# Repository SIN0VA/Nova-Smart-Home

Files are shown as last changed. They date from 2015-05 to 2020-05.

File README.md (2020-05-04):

# Nova Smart Home
## Introduction 
This is a Home Automation project that I did for my final year, it uses a Raspberry Pi that acts as a central board for controling a bunch of Arduino UNO  cards (RF Nodes). For this project I made 4 types of these RF nodes.  

  1. [RF Switches](Arduino Sketches and Schematics/Arduino RF Controlled Lightswitch/) (to switch any electrical appliance, it's implemented here for lights only).  
  2. PIR Nodes (A bunch of Arduino's coupled with PIR detectors for autolights).  
  3. A Sensor Node (An Arduino with special [Sensor Shield](https://github.com/SIN0VA/Nova-Smart-Home/tree/master/Arduino%20Sketches%20and%20Schematics/Arduino%20Sensor%20Node) : to collect readings on temperature, humidty and somke detection ).  
  4. An HVAC Controller (An Arduino with a special [HVAC Shield](Arduino Sketches and Schematics/Arduino Sensor Node/) to   control a "Conventional HVAC System"). I haven't tested this one, so you should tread carefully.  
<p align="center">
 
</p>  

The communication between the Raspberry Pi and the other nodes is achieved using the NRF24L01 RF module, each type of the RF nodes has its own Shield, except the light switch which is a RF light switch (Arduino compatible) based on an Atmega328p MCU and a relay.  

## Software Stack 
### Arduino Sketches
Each RF node has its owns sketch, the two types of nodes that send data to the Raspberry Pi are the PIR Node and the Sensor Node, the other two (the HVAC controller and the RF light switch) will only recieve commands from the Raspberry Pi.  

1. [RF Switch Sketch](Arduino Sketches and Schematics/Arduino RF Controlled Lightswitch/RF LightSwitch/RF LightSwitch.ino).  
2. [PIR Node Sketch](Arduino Sketches and Schematics/Arduino RF Motion Detection/Motion Detection/Motion Detection.ino).  
3. HVAC Controller Sketch (haven't made this one).  
4. [Sensor Node Sketch](Arduino Sketches and Schematics/Arduino Sensor Node/SensorNode/SensorNode.ino).  

If you can't make the Shields, just follow the schematics of every Shield and use wires (but you have to make the RF Switch to control lights).
### Raspberry Pi  
<p align="center">
  
</p>

Just to introduce the workings of this project a little bit, there are two programs ; a Node.JS app  which is an Express Web Server so people can turn off/on lights and things like that, If you're familiar with NodeJS Express check the two main files of the server the [ExpressJS Routes](HomeControlServer/routes/index.js) file and the [ExpressJS App ](HomeControlServer/app.js) file. For security reasons, this server uses SSL encryption and asks for a password and a username everytime someone tries to access this server.
The second app is a [Control Daemon](ControlDaemon/NovaHomeDaemon.cpp) coded with C++, this one controls and handles the requests from NodeJS Web Server (IPC via ZMQ sockets) and other RF nodes (via NRF24L01), it also performs the Home Automation side of things.
  
### Control Daemon Configuration  
The Nova Control Daemon is small process that controls the different RF nodes using the RF interface (NRF24L01), it waits for requests from the web server (when a user turn on/off/auto the lights from the browser). This is the heart of this system, it's the decision making engine of this Smart Home, I should note that temprature control uses a simple non-tested algorithme so this area might need some improvements. The autolights (based on motiond detection) and manual light control (using web server) work flawlessly. But this app needs a configuration, for now to configure the control daemon you have to check its [configuration file](/ControlDaemon/NovaHomeDaemon.cfg), I commented on every lines so it's pretty straightforward, later I will add the ability to configure the Dameon from a browser.

### Web Server How-To Install  
Just install NodeJS and copy the HomeControlServer. (The complete guide is coming...)

### Nova Home Daemon How-To Install  
Install the dependencies and compile NovaHomeDaemon. (Wait for the complete tutorial, it's gonna be easy)

### HomeRF Protocol 
I made this protocol to secure and manage the exchange of data and commands between the Raspberry Pi and the RF Nodes, this protocol sits on top of the RF24Network Library. It uses AES-128 for encryption and HMAC-SHA1 for authentication.
Here is a diagram for the HomeRF paquet and the structure of data encrypted inside of it :  
<p align="center">
  
</p>  

### Hardware Stack  
(Schematics explanations and design choices,...)

### What's working :  
These functions are tested and working properly :  
1. Autolights (motion detection, disabled/enabled at night/day).
2. Geolocation (sets the time to enable/disable the autolights function).  
3. Manual lights control from any web browser computers, tablets or smarthphones (thanks to responsive design).  
4. Secure Encryprion of RF data using the AES-128 Standard.  
5. SMS Alert in case of fire or smoke detection.  

### What's not Working :  
1. HMAC-SHA1 Authentication (gotta fix it).  
2. I haven't tested temprature and humidity control (the algorithme needs some improvment maybe a PID code).  
3. Call2Report (call the Smart Home and then it will report back with an SMS), this one is not tested.  

### IMPORTANT NOTE !
You can't sell, publish any of the code in here, it's free software under the GPLv3 licence.
Read the licence for more information.
When you use this project or any code of it especially in an academic paper, you have to link to this website.

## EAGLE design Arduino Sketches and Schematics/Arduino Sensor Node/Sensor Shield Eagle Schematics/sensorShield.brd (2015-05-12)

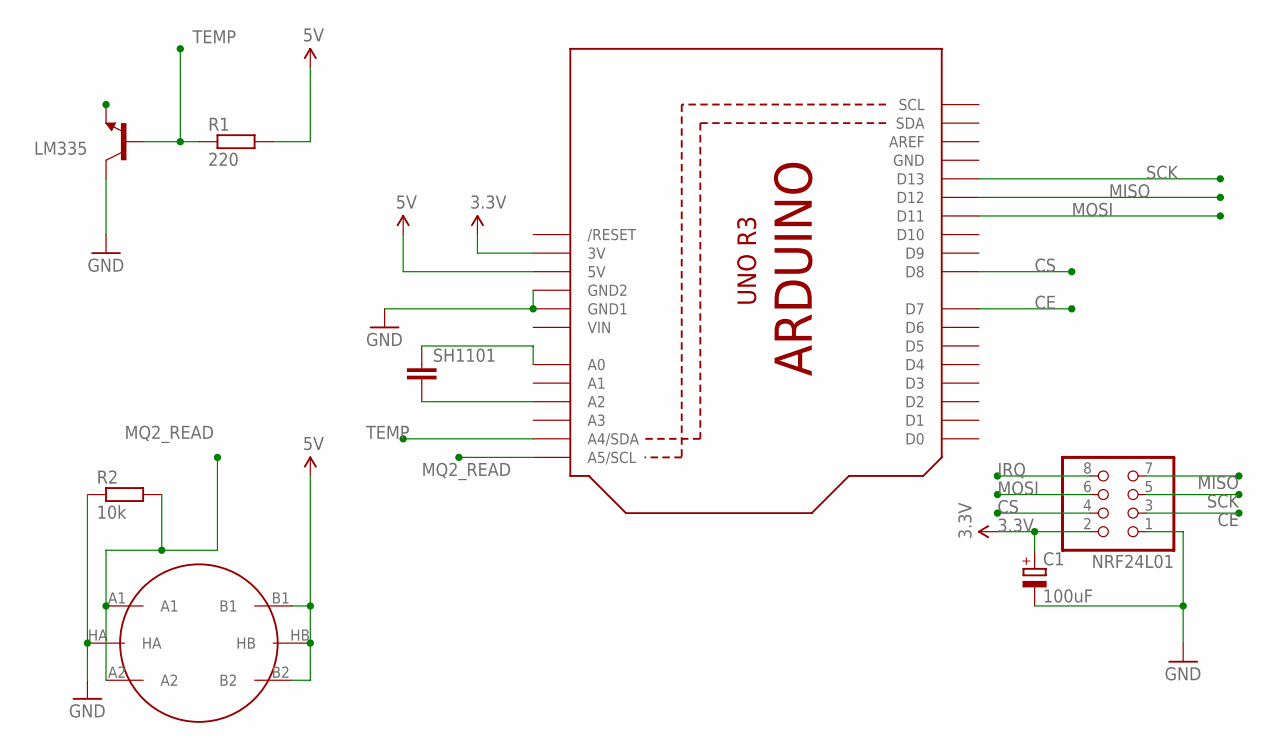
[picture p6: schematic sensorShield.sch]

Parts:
C1: 100uF; E5-6
LM335: TRANSISTOR_NPNTO-92-AMMO; TO-92-AMMO
NRF24L01: PINHD-2X4; 2X04
Q1: ARDUINOR3-NOIOREF-NOTEXT; ARDUINOR3-NOTEXT-NOIOREF
R1: 220; 0204/7
R2: 10k; 0204/7
SH1101: C-EU050-024X044; C050-024X044
U$1: METHANE_SENSOR; MQ-3

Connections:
3.3V: C1.+, NRF24L01.2, Q1.3V
5V: Q1.5V, R1.2, U$1.B1, U$1.B2, U$1.HB
CE: NRF24L01.3, Q1.D7
CS: NRF24L01.4, Q1.D8
GND: C1.-, LM335.3 (C), NRF24L01.1, Q1.GND, Q1.GND1, Q1.GND2, R2.1, U$1.HA
IRQ: NRF24L01.8
MISO: NRF24L01.7, Q1.D12
MOSI: NRF24L01.6, Q1.D11
MQ2_READ: Q1.A5 (A5/SCL), R2.2, U$1.A1, U$1.A2
unnamed: Q1.A2, SH1101.2
unnamed: Q1.A0, SH1101.1
SCK: NRF24L01.5, Q1.D13
TEMP: LM335.2 (B), Q1.A4 (A4/SDA), R1.1
VIN: Q1.VIN

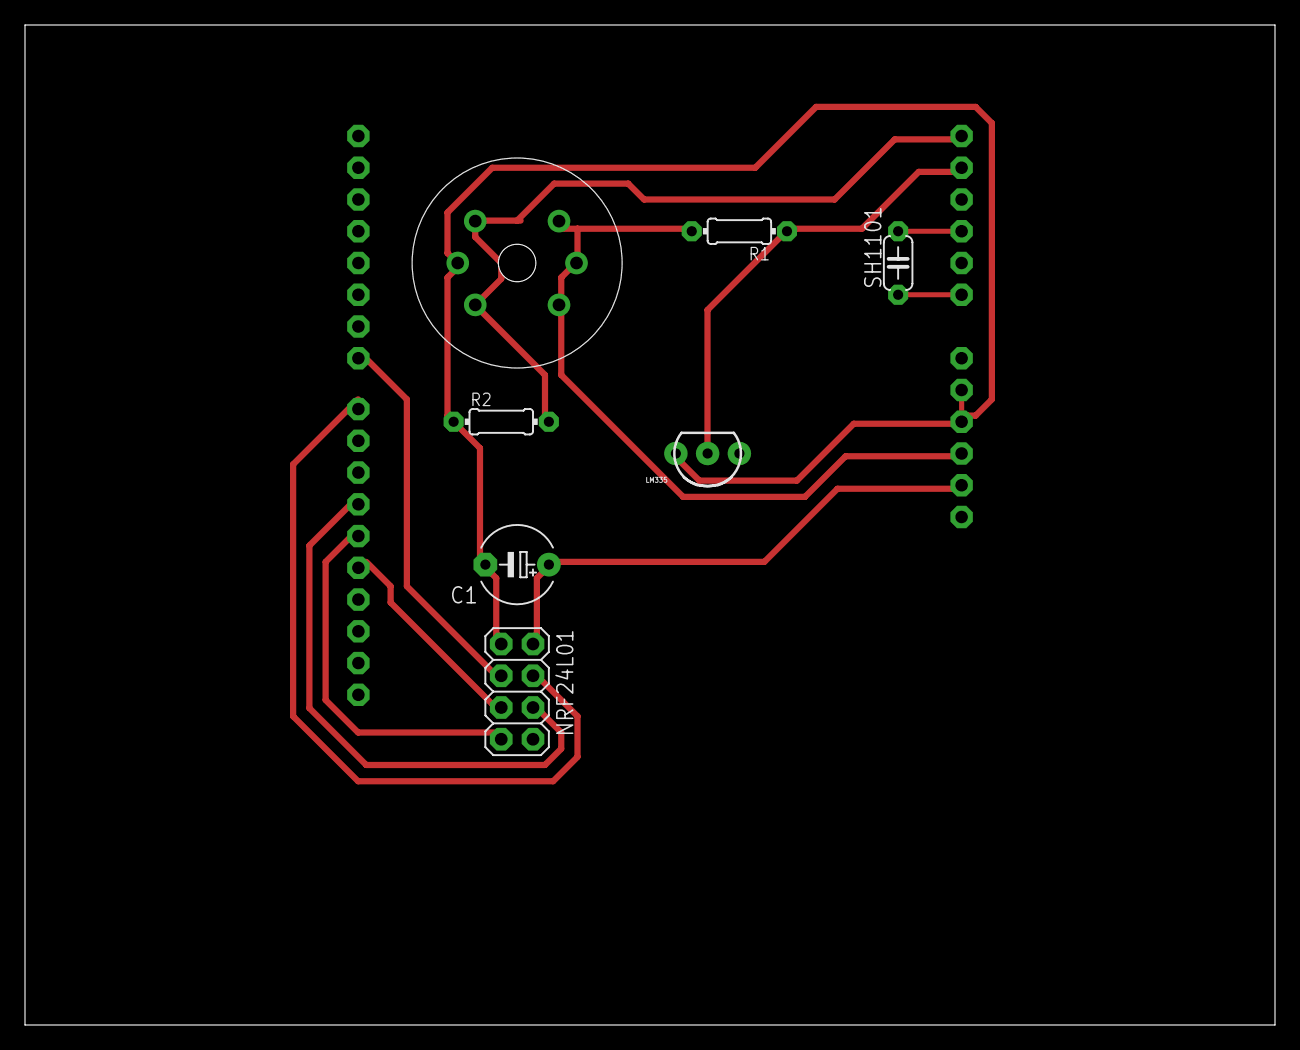
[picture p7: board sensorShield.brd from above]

Board: 2 copper layers, 100.0 x 80.0 mm, 8 parts (0 on the bottom side), 12 nets.

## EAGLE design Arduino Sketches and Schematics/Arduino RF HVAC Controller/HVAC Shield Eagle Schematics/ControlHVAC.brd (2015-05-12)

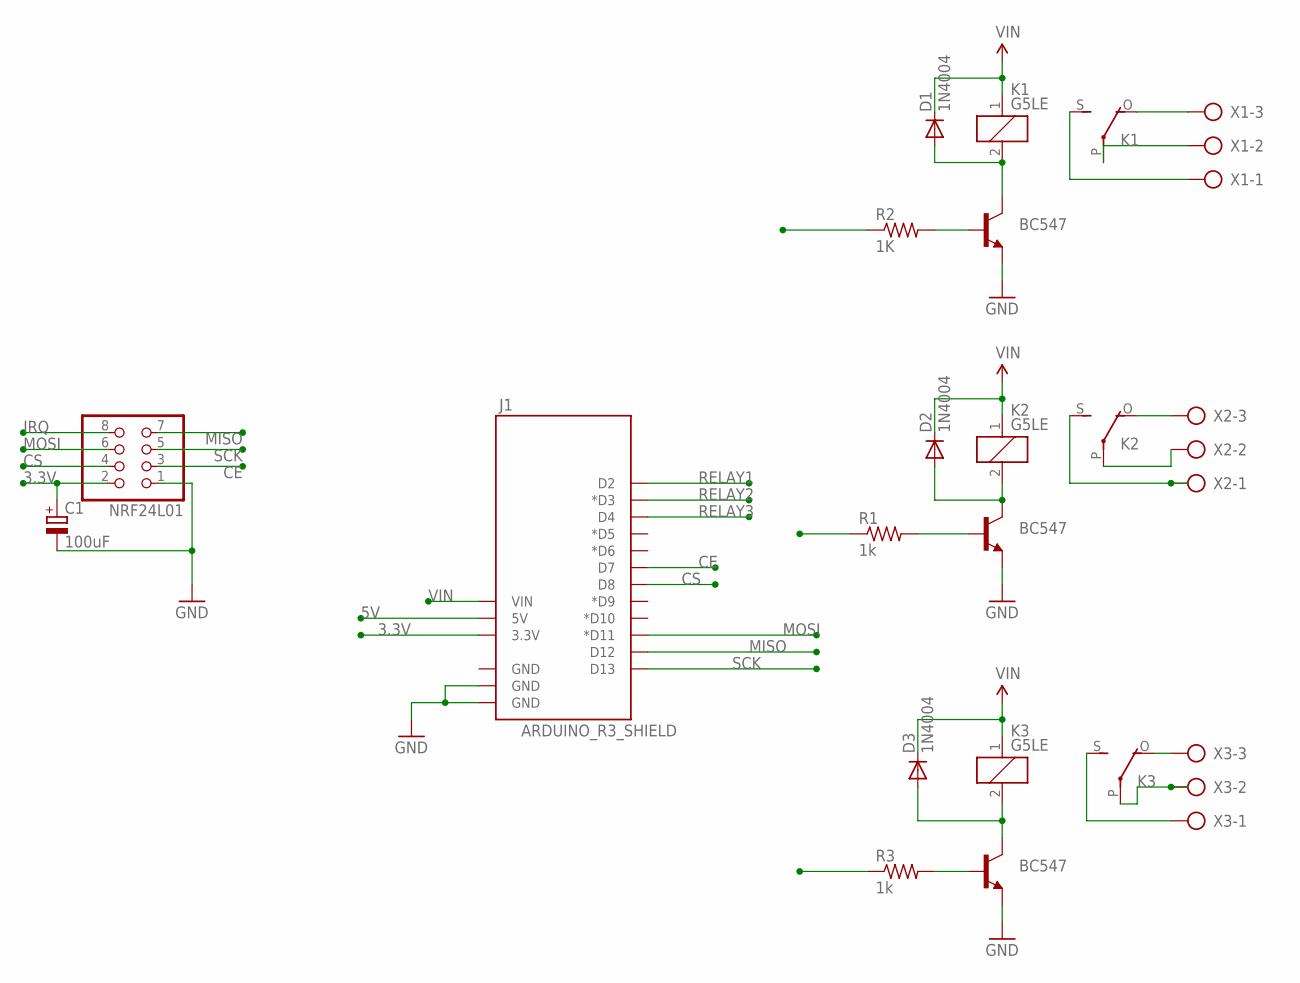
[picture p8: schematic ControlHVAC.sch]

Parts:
C1: 100uF; E5-6
D1, D2, D3: 1N4004; DO41-10
J1: ARDUINO_R3_SHIELD; UNO_R3_SHIELD
K1, K2, K3: G5LE
NRF24L01: PINHD-2X4; 2X04
R1, R3: 1k; 0204/7
R2: 1K; 0204/7
T1, T2, T3: BC547; TO92
X1, X2, X3: AK500/3-H

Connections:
3.3V: C1.+, J1.3.3V, NRF24L01.2
5V: J1.5V
CE: J1.D7, NRF24L01.3
CS: J1.D8, NRF24L01.4
GND: C1.-, J1.GND@0 (GND), J1.GND@1 (GND), NRF24L01.1, T1.1 (E), T2.1 (E), T3.1 (E)
IRQ: NRF24L01.8
MISO: J1.D12, NRF24L01.7
MOSI: J1.D11 (*D11), NRF24L01.6
unnamed: D3.A, K3.2, T3.3 (C)
unnamed: D2.A, K2.2, T2.3 (C)
unnamed: D1.A, K1.2, T1.3 (C)
unnamed: K2.O, X2.3
unnamed: K2.P, X2.2
unnamed: K2.S, X2.1
unnamed: K3.O, X3.3
unnamed: K3.P, X3.2
unnamed: K3.S, X3.1
unnamed: K1.S, X1.1
unnamed: K1.P, X1.2
unnamed: K1.O, X1.3
unnamed: R2.2, T1.2 (B)
unnamed: R1.2, T2.2 (B)
unnamed: R3.2, T3.2 (B)
RELAY1: J1.D2, R2.1
RELAY2: J1.D3 (*D3), R1.1
RELAY3: J1.D4, R3.1
SCK: J1.D13, NRF24L01.5
VIN: D1.C, D2.C, D3.C, J1.VIN, K1.1, K2.1, K3.1

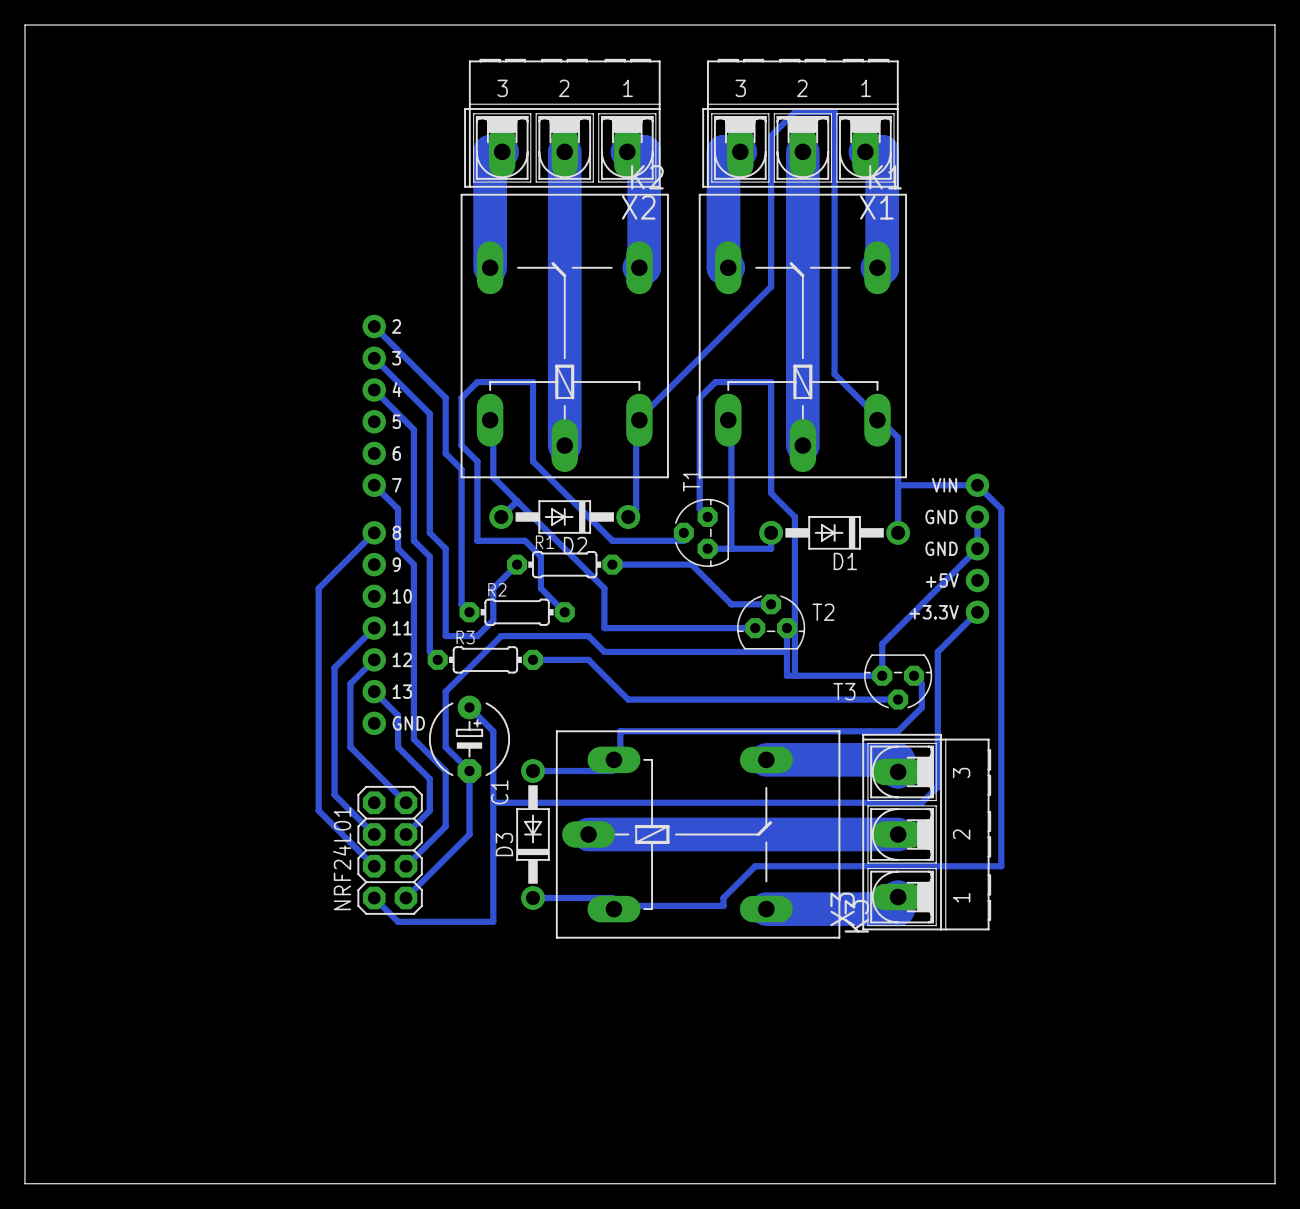
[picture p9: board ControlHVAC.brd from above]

Board: 2 copper layers, 100.0 x 92.7 mm, 18 parts (0 on the bottom side), 26 nets.

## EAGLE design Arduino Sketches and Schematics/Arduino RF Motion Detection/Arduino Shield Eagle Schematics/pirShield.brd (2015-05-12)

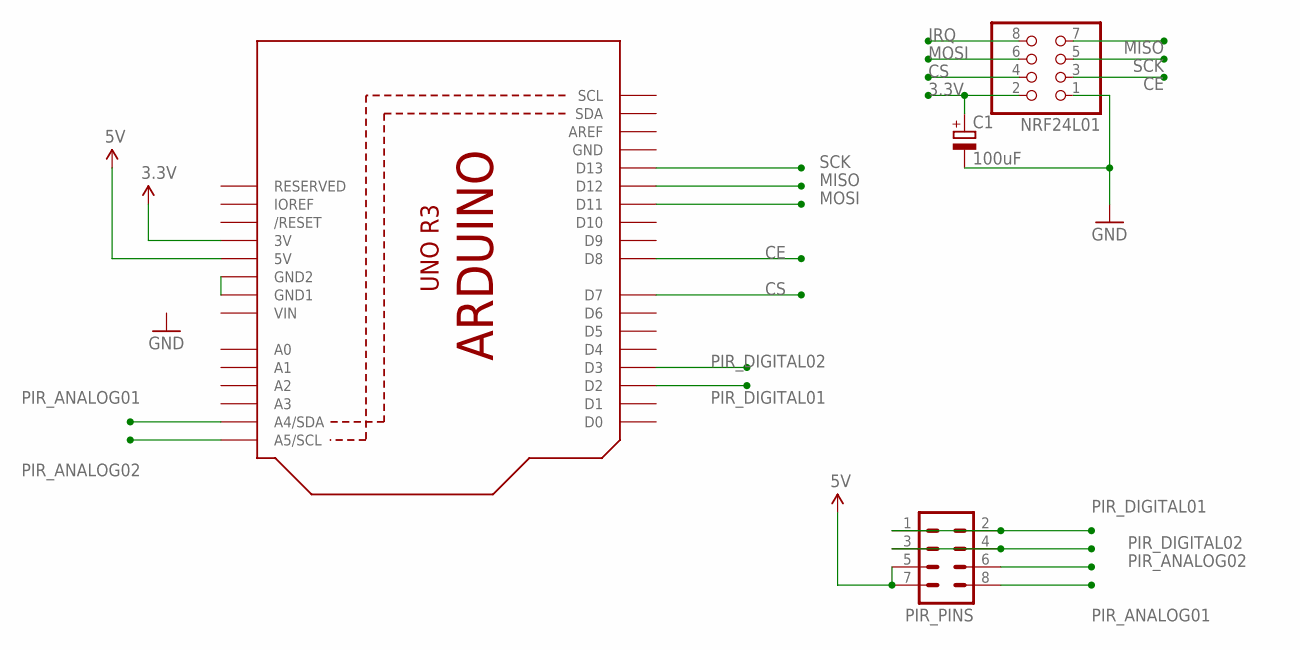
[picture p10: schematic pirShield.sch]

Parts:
C1: 100uF; E5-6
NRF24L01: PINHD-2X4; 2X04
PIR_PINS: MA04-2
U1: ARDUINOR3-BPLACE

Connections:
3.3V: C1.+, NRF24L01.2, U1.3V
5V: PIR_PINS.5, PIR_PINS.7, U1.5V
CE: NRF24L01.3, U1.D8
CS: NRF24L01.4, U1.D7
GND: C1.-, NRF24L01.1, U1.GND
IRQ: NRF24L01.8
MISO: NRF24L01.7, U1.D12
MOSI: NRF24L01.6, U1.D11
unnamed: U1.GND1, U1.GND2
PIR_ANALOG01: PIR_PINS.8, U1.A4 (A4/SDA)
PIR_ANALOG02: PIR_PINS.6, U1.A5 (A5/SCL)
PIR_DIGITAL01: PIR_PINS.1, PIR_PINS.2, U1.D2
PIR_DIGITAL02: PIR_PINS.3, PIR_PINS.4, U1.D3
SCK: NRF24L01.5, U1.D13
VIN: U1.VIN

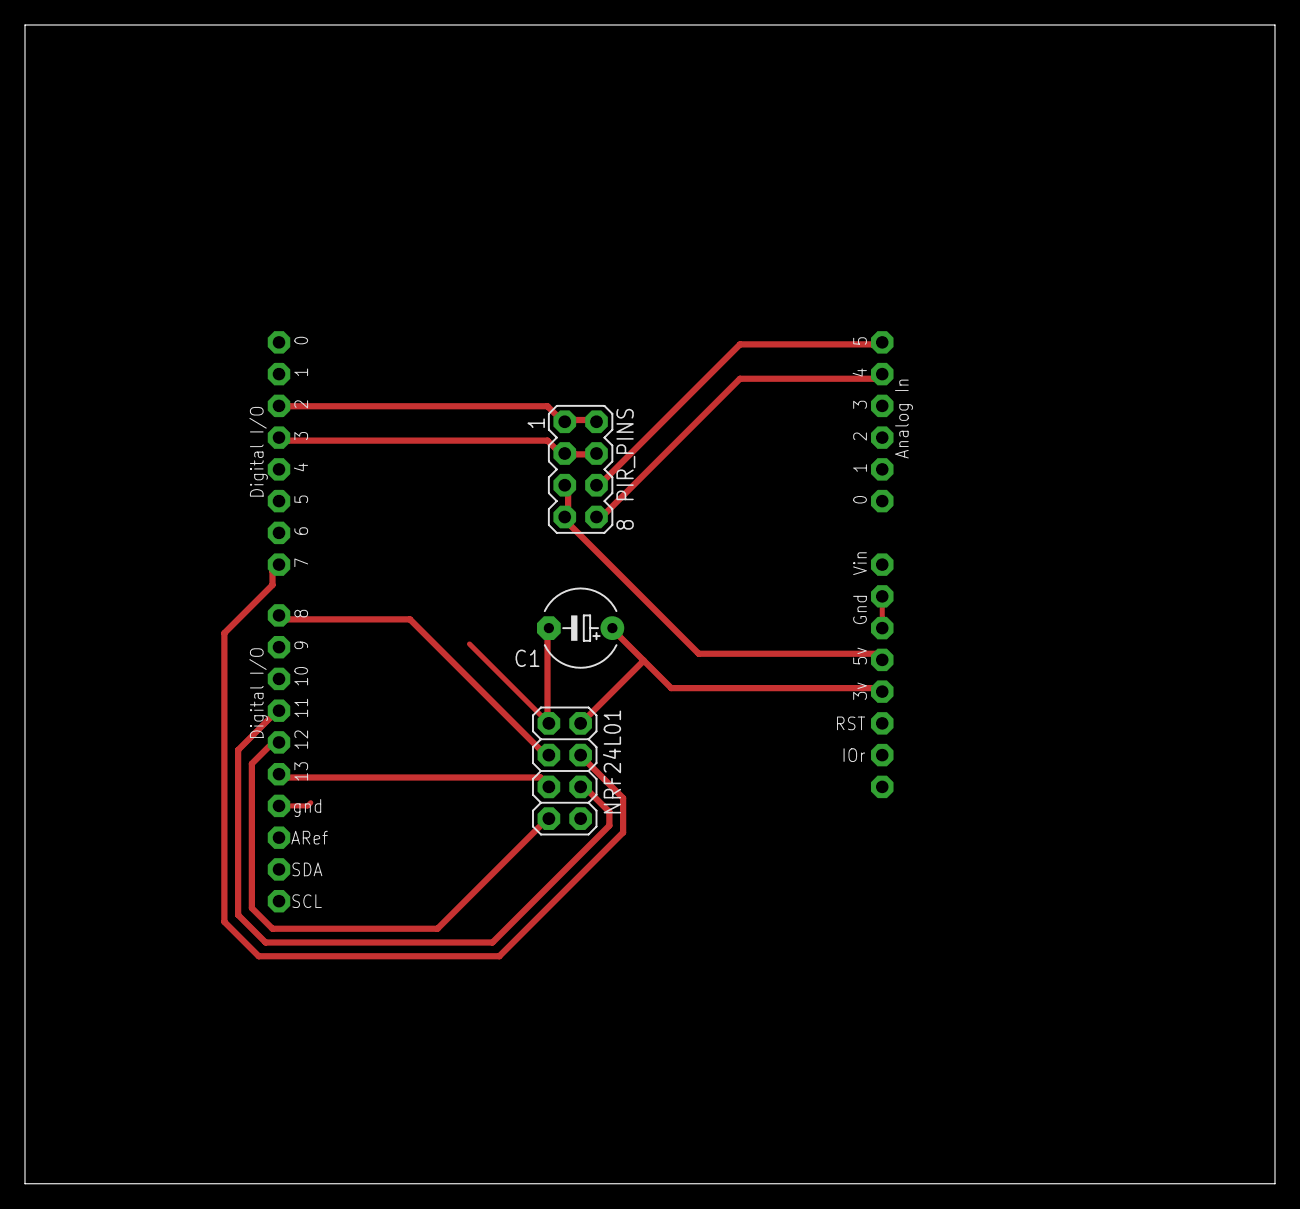
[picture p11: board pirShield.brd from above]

Board: 2 copper layers, 100.0 x 92.7 mm, 4 parts (0 on the bottom side), 13 nets.

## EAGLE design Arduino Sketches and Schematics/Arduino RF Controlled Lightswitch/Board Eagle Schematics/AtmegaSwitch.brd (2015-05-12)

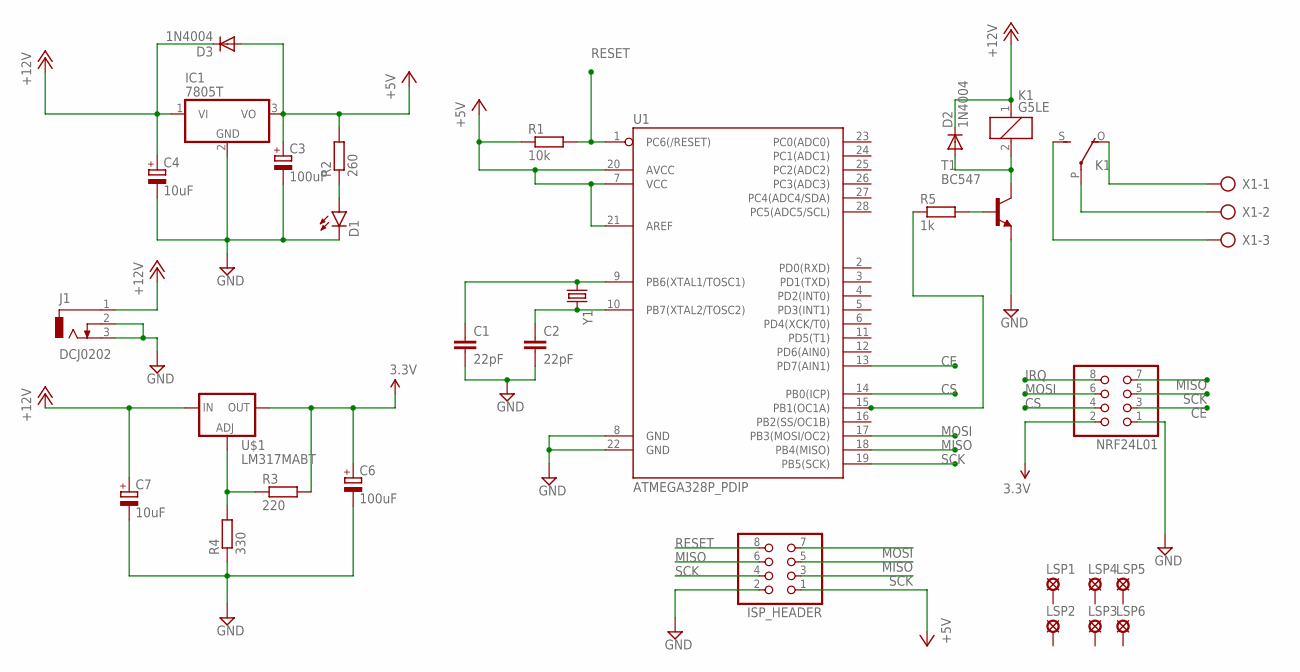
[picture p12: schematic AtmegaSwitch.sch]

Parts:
C1: 22pF; C025-025X050
C2: 22pF; C025-024X044
C3, C6: 100uF; E5-6
C4, C7: 10uF; E5-6
D1: LED5MM
D2, D3: 1N4004; DO41-10
IC1: 7805T; TO220H
ISP_HEADER: PINHD-2X4; 2X04
J1: DCJ0202
K1: G5LE
LSP1, LSP2, LSP3, LSP4, LSP5, LSP6: LSP10
NRF24L01: PINHD-2X4; 2X04
R1: 10k; 0204/7
R2: 260; 0204/7
R3: 220; 0204/7
R4: 330; 0204/7
R5: 1k; 0204/7
T1: BC547; TO92
U1: ATMEGA328P_PDIP; DIL28-3
U$1: LM317MABT; TO220L1
X1: AK500/3-H
Y1: CRYSTALHC49US; HC49US

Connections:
3.3V: C6.+, NRF24L01.2, R3.2, U$1.2 (OUT)
+5V: C3.+, D3.A, IC1.3 (VO), ISP_HEADER.1, R1.1, R2.2, U1.7 (VCC), U1.20 (AVCC), U1.21 (AREF)
+12V: C4.+, C7.+, D2.C, D3.C, IC1.1 (VI), J1.1, K1.1, U$1.3 (IN)
CE: NRF24L01.3, U1.13 (PD7(AIN1))
CS: NRF24L01.4, U1.14 (PB0(ICP))
GND: C1.2, C2.2, C3.-, C4.-, C6.-, C7.-, D1.K (C), IC1.2 (GND), ISP_HEADER.2, J1.2, J1.3, NRF24L01.1, R4.1, T1.1 (E), U1.8 (GND), U1.22 (GND)
IRQ: NRF24L01.8
MISO: ISP_HEADER.5, ISP_HEADER.6, NRF24L01.7, U1.18 (PB4(MISO))
MOSI: ISP_HEADER.7, NRF24L01.6, U1.17 (PB3(MOSI/OC2))
unnamed: C1.1, U1.9 (PB6(XTAL1/TOSC1)), Y1.1
unnamed: C2.1, U1.10 (PB7(XTAL2/TOSC2)), Y1.2
unnamed: D1.A, R2.1
unnamed: D2.A, K1.2, T1.3 (C)
unnamed: K1.P, X1.2
unnamed: K1.O, X1.1
unnamed: K1.S, X1.3
unnamed: R3.1, R4.2, U$1.1 (ADJ)
unnamed: R5.2, T1.2 (B)
unnamed: R5.1, U1.15 (PB1(OC1A))
RESET: ISP_HEADER.8, R1.2, U1.1 (PC6(/RESET))
SCK: ISP_HEADER.3, ISP_HEADER.4, NRF24L01.5, U1.19 (PB5(SCK))

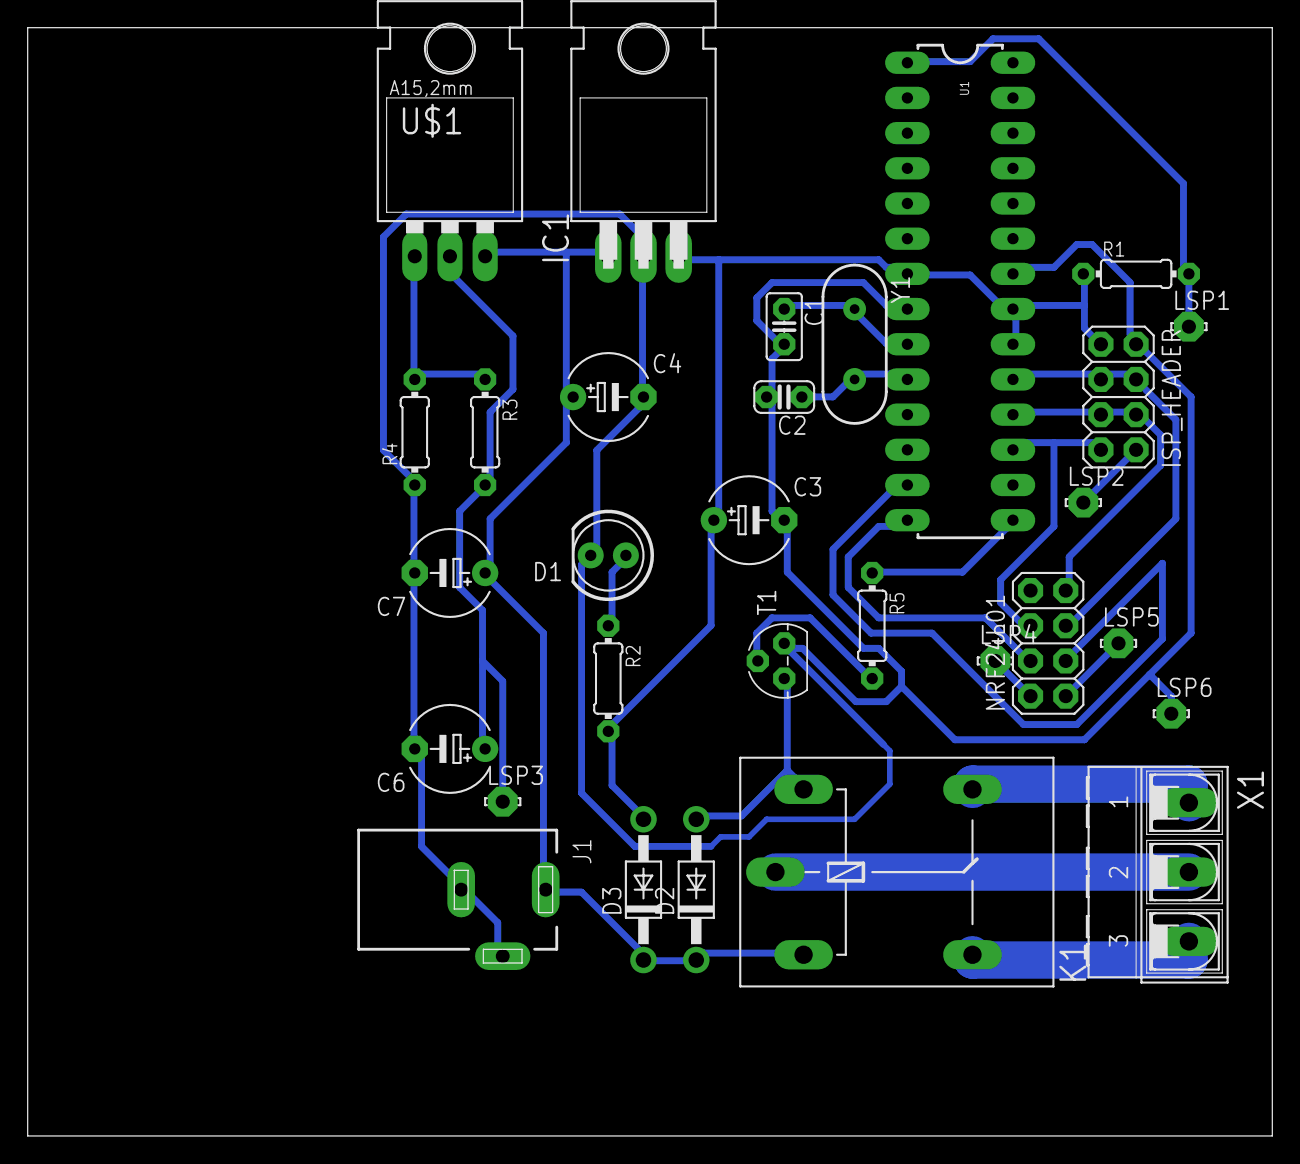
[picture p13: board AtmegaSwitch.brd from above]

Board: 2 copper layers, 89.8 x 80.0 mm, 30 parts (0 on the bottom side), 20 nets.

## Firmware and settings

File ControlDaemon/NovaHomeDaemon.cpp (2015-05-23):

//***************************************************************//
//********************Main Control Daemon************************//
//**********************S!NOVA 2015******************************//
//***************************************************************//
#include <iostream>
#include <string>
#include <fstream>
#include "zmq.hpp"
#include <zmq.h>
#include <zmq_utils.h>
#include <RF24/RF24.h>
#include <RF24Network/RF24Network.h>
#include <time.h>
#include <libconfig.h++>

#include <stdint.h>
#include "trng.h"
#include "AES.h"
#include "sha1.h"
#include <bitset>
#include <ctime>
#include <iomanip>
#include <curl/curl.h>
#include <cmath>
#include <string>
#include "rapidjson/document.h"
#include "rapidjson/writer.h"
#include "rapidjson/rapidjson.h"
#include "zhelpers.hpp"
#include <rapidjson/filereadstream.h>
#include "HomeRF.h"
#include <stdio.h>
#include <stdlib.h>
#include <gnokii.h>
#include <signal.h>
#include <unistd.h>
#define _(x) x

/////////////////////////////////////////////////////
using namespace rapidjson;
using namespace std;
using namespace libconfig;
using namespace zmq;

/////////////////////////////////////////////////////GSM
static void businit(void);
static void busterminate(void) ;

///////////////////////////////////////// Encryption Setup

int bits = 128;
uint8_t hmacKey1[] = { 0x00, 0x01, 0x02, 0x03, 0x04, 0x05, 0x06, 0x07, 0x08,
		0x09, 0x0a, 0x0b, 0x0c, 0x0d, 0x0e, 0x0f, 0x10, 0x11, 0x12, 0x13, 0x14,
		0x15, 0x16, 0x17, 0x18, 0x19, 0x1a, 0x1b, 0x1c, 0x1d, 0x1e, 0x1f, 0x20,
		0x21, 0x22, 0x23, 0x24, 0x25, 0x26, 0x27, 0x28, 0x29, 0x2a, 0x2b, 0x2c,
		0x2d, 0x2e, 0x2f, 0x30, 0x31, 0x32, 0x33, 0x34, 0x35, 0x36, 0x37, 0x38,
		0x39, 0x3a, 0x3b, 0x3c, 0x3d, 0x3e, 0x3f };
byte key[] = { 0x53, 0xDE, 0xF0, 0x33, 0x7F, 0x1E, 0x59, 0xB3, 0x0A, 0x38, 0xF4,
		0xC0, 0x11, 0x81, 0xFE, 0x9C };

//////////////////////////////////RF Setup
RF24 radio(RPI_V2_GPIO_P1_15, BCM2835_SPI_CS0, BCM2835_SPI_SPEED_8MHZ); // Setup for GPIO 22 CE and CE1 CSN with SPI Speed @ 8Mhz
RF24Network network(radio);
struct gn_statemachine *state;
int quit = 0;
/////////////////////////////////////////////
typedef struct {
	char switchid;
	char state;
}node_message;
//////////////////////////////////////////////

int main(int argc, char** argv) {

	int call_id = 0;
	gn_call* pcall;
	bool thermostat = false ;
	bool heater=false;
	bool ac=false;
	bool auto_light=true;
	bool call2report=false;
	bool day_saving=false;
	bool geolocation=false;
	float maintained_temp=0;  //read from node.js Home Control Server ,when thermostat activated
	float out_temp ;
	float out_humid;
	float current_tem=0;
	float current_hum=0;
	float current_gas=0;
	//string city_name;
	string wan_ip;
	string country;
	string city;
	string lights_evening;
	string lights_off_ambient_off;
	////////////////////////////////////////////////////////////////////
	cout<< "                   _______________________________"<<endl;
	cout<< "******************|+++++++++++++++++++++++++++++++|***************************"<<endl;
	cout<< "******************|+|===========================|+|***************************"<<endl;
	cout<< "******************|+| Smart Home Control Daemon |+|***************************"<<endl;
	cout<< "******************|+|  Final Year Project 2015  |+|***************************"<<endl;
	cout<< "******************|+|     By Adil Benabdallah   |+|***************************"<<endl;
	cout<< "******************|+|      (Debug. Console)     |+|***************************"<<endl;
	cout<< "******************|+|___________________________|+|***************************"<<endl;
	cout<< "******************|+++++++++++++++++++++++++++++++|***************************"<<endl;
	cout<<endl;
	bool day_time=false;                //turn off all lights for late time, and activating ambient lights
	printf("Loading configuration file ''NovaHomeDaemon.cfg'' ... \n");
	Config cfg;
	/////////////////////////////////////////////Loading Config Variables///////////////////////////////////////
	try {
		cfg.readFile("NovaHomeDaemon.cfg");
	}  catch(const FileIOException &fioex) {
		std::cerr << "I/O error while reading file." << std::endl;
		return(EXIT_FAILURE);
	} catch(const ParseException &pex) {
		std::cerr << "Parse error at " << pex.getFile() << ":" << pex.getLine()
				<< " - " << pex.getError() << std::endl;
		return(EXIT_FAILURE); }
	Setting &root = cfg.getRoot();
	unsigned int ctemp_l = cfg.lookup("ctemp_l");
	cout<<"Critical Lowest Temperature set to : " << ctemp_l << " °C "<< endl;
	unsigned int ctemp_h = cfg.lookup("ctemp_h");
	cout<<"Critical Highest Temperature set to : " << ctemp_h << " °C "<< endl;
	unsigned int temp_h = cfg.lookup("temp_h");
	cout<<"Hysteresis  Temperature set to : " << temp_h << " °C "<< endl;
	unsigned int cGas = cfg.lookup("cgas");
	cout<<"Critical Gas level set to : " << cGas <<" ppm "<< endl;
	unsigned int cHumid = cfg.lookup("chumid");           //Critical Humidty
	cout<<"Humidity Alert level set to : " << cHumid <<"% "<< endl;

	unsigned int light_timer = cfg.lookup("light_timer");           //Critical Humidty
	cout<<"Auto-lights timer set to : " << light_timer/1000.0 <<" seconds ."<< endl;

	unsigned int this_node= cfg.lookup("hub_addr");
	cout<<"RF Address of this RF Hub : "<< setfill('0')<< setw(2)<< this_node << endl;
	unsigned int thermostat_addr= cfg.lookup("thermostat_addr");
	cout<<"RF Address of the HVAC controller : " << setfill('0')<< setw(2)<< thermostat_addr << endl;
	unsigned int ambient_addr= cfg.lookup("ambient_addr");
	cout<<"Ambient Lights (at night) controller address : " << setfill('0')<< setw(2)<<ambient_addr << endl;
	const Setting &PSpairs = root["pirSwitchPairs"];
	int count = PSpairs.getLength();
	cout << "Number of PIR sensor/Light Switch pairs : " << count << " pairs ."
			<< endl;

	unsigned int pairsVector[count * 2]; //Array for pairs ,each pir_addr is followed by light_addr
	for (int i = 0; i < count; ++i) {
		const Setting &pair = PSpairs[i];
		unsigned int pir_addr;
		unsigned int light_addr;
		pair.lookupValue("pir_addr", pir_addr);
		pair.lookupValue("light_addr", light_addr);
		cout << "PIR Address : " <<pir_addr << " ; Light Switch Address : " << light_addr <<endl;
		if ((2*i)%2==0){
			pair.lookupValue("pir_addr", pairsVector[2*i]);
			pair.lookupValue("light_addr", pairsVector[2*i+1]);
		}
	}


	/* if(array)
	  {
	    for(i = 0; i < config_setting_length(array); i++)
	    {
	      long val = config_setting_get_int_elem(array, i);
	      printf("value [%i]: %ld\n", i, val);
	    }
	  }*/

	call2report = cfg.lookup("call2report");
	if (call2report)cout<<"Call2report enabled ." << endl; else
		cout<<"Call2report disabled  ." << endl;

	day_saving = cfg.lookup("day_saving");
	if (day_saving)cout<<"Lights day saving enabled ." << endl; else
		cout<<"Lights day saving disabled  ." << endl;

	Setting &alert_phones = root["alert_phones"];
	int number_of_phones = alert_phones.getLength();
	cout << "Number of phones in the emergency list , " << number_of_phones << " phones";
	std::string phonesVector[number_of_phones];
	for (int i = 0; i < number_of_phones; ++i) {
		string phone = alert_phones[i];
		phonesVector[i]=phone;
		/*phonesVector.lookupString();
	      phonesVector.lookupString();*/
		//phonesVector[i]=alert_phones.lookup(alert_phones[i]);
		cout<<", "<< phonesVector[i] ;
	}
	cout<<"."<<endl;
	if (number_of_phones<2) cout << "It is recommended to set at least three phone numbers ." << endl ;
	string lights_off_ambient_on = cfg.lookup("lights_off_ambient_on");
	cout<<"Turning off the main lights ,and switching to ambient lights (Late night) at : " << lights_off_ambient_on << endl;
	geolocation = cfg.lookup("geolocation");
	if (geolocation){
		cout<<"The function of geolocation is enabled." << endl;
		get_JSON("freegeoip.net/json","geo.json");
		cout<<"Auto-Geolocation setting is on ..."<<endl;
		FILE* pFile = fopen("geo.json", "rb");
		char buffer[65536];
		FileReadStream is(pFile, buffer, sizeof(buffer));
		Document document;
		document.ParseStream<0, UTF8<>, FileReadStream>(is);
		city=document["city"].GetString();
		country=document["country_name"].GetString() ;
		wan_ip=document["ip"].GetString() ;
		double longitude=document["longitude"].GetDouble() ;
		double latitude=document["latitude"].GetDouble() ;
		cout << "Country Detected : " << country << endl;
		cout<< "Region : " << document["region_name"].GetString()<<endl;
		cout << "City Detected : " << city << endl;
		cout << "Longitude : "<< longitude <<endl;
		cout << "Latitude : "<< latitude <<endl;
		cout << "External IP  : " << wan_ip << endl;
		string weather = "http://api.openweathermap.org/data/2.5/weather?lat="+to_string(latitude)+"&lon="+to_string(longitude)+"&units=metric";
		get_JSON(weather.c_str(),"weather.json");
		FILE* pFile2 = fopen("weather.json", "rb");
		char buffer2[65536];
		FileReadStream is2(pFile2, buffer2, sizeof(buffer2));
		Document document2;
		document2.ParseStream<0, UTF8<>, FileReadStream>(is2);
		time_t t = (time_t) document2["sys"]["sunrise"].GetInt();
		struct tm *tm = localtime(&t);
		char date2[10];
		strftime(date2, sizeof(date2), "%R", tm);
		lights_off_ambient_off = string(date2);
		cout<<"Turning off all lights (Morning) at  : " << lights_off_ambient_off << endl;
		t = (time_t) document2["sys"]["sunset"].GetInt();
		tm = localtime(&t);
		strftime(date2, sizeof(date2), "%R", tm);
		lights_evening = string(date2);
		cout<<"Turning on the main lights (Evening) at  : " << lights_evening << endl;
		out_temp = document2["main"]["temp"].GetDouble();
		cout << "Temperature outside the House : " << out_temp << "C°" << endl ;
		out_humid = document2["main"]["humidity"].GetDouble();
		cout << "Humidity outside the House : " << out_humid << "%" << endl ;
	} else {
		root.lookupValue("city_name", city);
		cout<<"The function of Geolocation is disabled" << endl;
		cout<<"Location is manually configured to : "<< city<<endl;
		root.lookupValue("lights_off_ambient_off", lights_off_ambient_off);
		//lights_off_ambient_off =(string) cfg.lookup("lights_off_ambient_off");
		cout<<"Turning off all lights (Morning) at  : " << lights_off_ambient_off << endl;
		//lights_evening = (string)cfg.lookup("lights_evening");
		root.lookupValue("lights_evening", lights_evening);
		cout<<"Turning on the main lights (Evening) at  : " << lights_evening << endl;
	}
	/////////////////////////////////////////////Loading Config Variables Ends Here///////////////////////////////////////

	/////////////////////////////////////////////Start RF interface and ZMQ Sockets///////////////////////////////////////
	radio.begin();
	network.begin(/*channel*/90, /*node address*/this_node);
	time_t rawtime;
	struct tm * timeinfo;
	time (&rawtime);
	timeinfo = localtime (&rawtime);
	char *buffer;
	strftime (buffer,80,"Now it's %I:%M%p.",timeinfo);
	printf ("Current local time and date: %s \n", asctime(timeinfo));
	usleep(10);
	//radio.printDetails();
	cout<<"Listening for RF packets ..."<<endl;
	double last_pir_t;
	double last_;
	zmq::context_t context (1);
	zmq::context_t context2 (2);
	socket_t socket (context, ZMQ_PULL);
	socket.connect("tcp://127.0.0.101:5555");

	zmq::socket_t responder(context, ZMQ_REP);
	responder.bind("tcp://127.0.0.104:5559");

	int i=0;
	/////////////////////////////////////////////////The Daemon Loop///////////////////////////////////////////////////////////
	while (1) {
		////////////////////////////////////Checking the time for day and night lights control/////////////////////////////////
		if(day_saving==true) {
		day_time=checkoffTime(lights_off_ambient_on,lights_evening);
		usleep(10);}
		/////////////////////////////////Sending Temprature to Web Server////////////////////////////////////////
		message_t message1;
		int error1=responder.recv(&message1,ZMQ_NOBLOCK);
		if(error1!=0&&error1!=-1) {
		cout<<"Received temperature request from server ...";
        usleep (2);
        string json="{\"temp\":"+ to_string(round(current_tem)) +",\"humid\":"+ to_string(round(current_hum)) +"}";
        message_t reply(json.length());
        memcpy ((void *) reply.data (), json.c_str(), json.length());
        responder.send (reply);
        cout<<"reply sent ."<<endl;
		}
		////////////////////////////////////////ZMQ Listener ,Looking for Home Control Server Events /////////////////////////////////
		usleep(200);
		network.update();
		message_t message;
		int error=socket.recv(&message,ZMQ_NOBLOCK);
		if(error!=0&&error!=-1) {
			string mess = string(static_cast<char*>(message.data()), message.size());
			cout << mess << endl;
			Document document;
			document.Parse(mess.c_str());
			string switchid=document["switchid"].GetString() ;
			string state=document["state"].GetString();
			if (state.compare(1,3,"uto")==0)	{
				bool send=true;
				unsigned int light_addr = pairsVector[2*(stoi(switchid))+1];
				send_rfcommand('L', heater, ac, send,light_timer,light_addr,key,bits,hmacKey1,network);
				cout << "Command from Home Control Web Server: Auto lights are activated ."<<endl;
				auto_light=true;
			} else if (state.compare(1,1,"n")==0){
				bool send=true;
				unsigned int light_addr = pairsVector[2*(stoi(switchid))+1];
				cout << "Command from Home Control Web Server: "<< light_addr<<" Lights are on ." <<endl;
				send_rfcommand('N', heater, ac, send,5000,light_addr,key,bits,hmacKey1,network);
				auto_light=false;
			} else if (state.compare(1,2,"ff")==0){
				bool send=true;
				unsigned int light_addr = pairsVector[2*(stoi(switchid))+1];
				cout << "Command from Home Control Web Server: "<< light_addr<<" Lights are off ."<<endl;
				send_rfcommand('F', heater, ac, send,5000,light_addr,key,bits,hmacKey1,network);
				auto_light=false;
			}
		}
		//////////////////////////////////////////////////////////////////
		bool send_t=false;
		rf_paquet rfpaquet2 ;

		/////////////////////////////////////////RF Packets Control
		if (network.available()) {
			RF24NetworkHeader header;
			network.read(header, &rfpaquet2, sizeof(rfpaquet2));
			//Sha1.initHmac(hmacKey1, 64);
			//Sha1.print((const char*) &rfpaquet2.aespaquet);
			//aes_paquet aespaquet;
			//memcpy(&aespaquet,&rfpaquet2.aespaquet,24);
			cout << "Received packet ... ************************************************************************" << endl;
			cout<<"Recieved Aespaquet in hex : "<<endl ;
			printHash((byte*)&rfpaquet2.aespaquet,24);
			cout<<"Recieved packet in hex : "<<endl ;
			printHash((byte*)&rfpaquet2,44);
			Sha1.initHmac(hmacKey1,64);
			Sha1.print((const char*)&(rfpaquet2.aespaquet));
			uint8_t * hmac_tag=Sha1.resultHmac();
			//memcpy(hmac_tag,Sha1.resultHmac(),20);
			cout<<"Calc HMAC in hex : "<<endl ;
			printHash((byte*)hmac_tag,20);
			cout<<"Pack HMAC in hex : "<<endl ;
			printHash((byte*)rfpaquet2.hmac_tag,20);
			//if (strncmp ((const char *)hmac_tag,(const char *)rfpaquet2.hmac_tag,20) == 0) { // Test HMAC
			if (true) { // Bypassing HMAC verification, will test only encryption
				long int i_v = rfpaquet2.aespaquet.i_v;
				cout <<"IV : ";
				cout<<i_v<<endl;
				cout<<"HMAC Success !"<<endl;
				byte dec_bytes2[16];
				byte iv2 [16];
				AES aes;
			    aes.set_IV((long int)rfpaquet2.aespaquet.i_v);
				aes.get_IV(iv2);
				//memcpy(iv2,&(rfpaquet2.aespaquet.i_v),sizeof(rfpaquet2.aespaquet.i_v));
				aes.do_aes_decrypt(rfpaquet2.aespaquet.enc_data,16,dec_bytes2,key,bits,iv2);          //if it didn't work change aes.get_size() to 15
				cout<<"********************************";
				if (rfpaquet2.aespaquet.paquet_type=='S') cout <<"Sensor Packet Identified  *********************************"<<endl;
				else if (rfpaquet2.aespaquet.paquet_type=='P') cout<<"PIR Packet Identified *********************************"<<endl;
				cout <<"HMAC tag : ";
				printHash((byte*)rfpaquet2.hmac_tag,20);
				cout <<"The RF Packet in hex : " ;
				printHash((byte*)&rfpaquet2,44);
				cout <<"Encrypted  bytes : ";
				printHash(rfpaquet2.aespaquet.enc_data,sizeof(rfpaquet2.aespaquet.enc_data));
				if (rfpaquet2.aespaquet.paquet_type=='S') {
					sensor_data dec_data;
					memcpy(&dec_data, dec_bytes2, sizeof(sensor_data));    //If messed up output change sizeof(sensor_data) to sizeof(dec_bytes2)
					cout <<"Decrypted bytes : ";
					printHash((byte*)&dec_data,sizeof(dec_data));
					current_tem=dec_data.tem;
					cout<<"Temperature : "<<to_string(dec_data.tem)<<"C°" <<endl;
					current_hum=dec_data.hum;
					cout<<"Humidity  : "<<to_string(dec_data.hum)<<"%" <<endl;
					current_gas=dec_data.gas;
					cout<<"Gas levels : "<<to_string(dec_data.gas)<<"ppm" <<endl;
					if (dec_data.gas>cGas) {//SMS Notification
						cout << "WARNING !! Possible smoke or gas leak in the house !" <<endl;
						for (int i=0;i<number_of_phones;i++){
							string sms_alert="echo \"Warning ! Possible Fire or Gas Leak . Attention ! Possibilite d'incendie ou fuite de gas ! - Test SmartHome  A.B. PFE 2015 ! Je vous remercie  ! "
									" \" | gnokii --sendsms "+phonesVector[i]+" &";
							system(sms_alert.c_str());
							cout << "An Alert SMS has been sent to " << phonesVector[i] <<endl;
							//sleep(2);
						}

					}

					/////////////////////////////////////////////////////Critical Temperatures Control
					if (thermostat==false) {
						if (dec_data.tem<ctemp_l && heater==false) {
							cout<<"Heater Activated ."<<endl;           //send the message Heat and Fan enabled
							heater=true;
							send_t=true;
						}
						else if(dec_data.tem>ctemp_l+temp_h&&heater==true){
							cout<<"Heater shutting down ."<<endl; //send the message Heat and Fan shut down
							heater=false;
							send_t=true;
						}
						if (dec_data.tem>ctemp_h&&ac==false) {
							cout<<"Air Conditioner  Activated ."<<endl; //send the message A/C and Fan enabled
							ac=true;
							send_t=true;
						}
						else if(dec_data.tem<ctemp_h-temp_h&&ac==true){
							cout<<"Air Conditioner shutting down ."<<endl; //send the message A/C and Fan shutdown
							ac=false;
							send_t=true;
						}  /////////////////////////Thermostat Control //////////////
					} else {
						if (dec_data.tem < maintained_temp-temp_h && heater == false) {
							cout << "Heater Activated ." << endl;
							heater = true;
							send_t=true;
						} else if (dec_data.tem > maintained_temp + temp_h && heater == true) {
							cout << "Heater shutdown ." << endl;
							heater = false;
							send_t=true;
						} else if (dec_data.tem > maintained_temp+temp_h+1 && ac == false) {
							cout << "Air Conditioner  Activated ." << endl;
							ac = true;
							send_t=true;
						} else if (dec_data.tem < maintained_temp-temp_h+1 && ac == true) {
							cout << "Air Conditioner  shutdown ." << endl;
							ac = false;
							send_t=true;
						}
					}
					send_rfcommand('T', heater, ac, send_t,5000,thermostat_addr,key,bits,hmacKey1,network);
					usleep(10);
				} else if (rfpaquet2.aespaquet.paquet_type == 'P' && auto_light==true && day_time==false) {
					bool send=true;
					unsigned int addrr;
					memcpy(&addrr,dec_bytes2,2);
					//memcpy(&dec_data, dec_bytes2, sizeof(pir_data));
					cout << "PIR trip from node "<< addrr<<" received !" << endl;
					unsigned int light_addr = find_lightaddr(pairsVector,addrr,count);
					send_rfcommand('L', heater, ac, send,light_timer,light_addr,key,bits,hmacKey1,network);
					usleep(10);
				} else cout << "Lights are set to manual control from web server ,or it's day time ! No light control packets are sent ." <<endl;

			}

			else cout<<"Wrong HMAC . Packet Dropped  ! " << endl;
		}
		usleep(1);
		//////////////////////////////////////////////////////////GSM Call Listener /////////////////
		//fprintf(stderr, _("Waiting for a call.\n"));
		////////////////////////////////////////////////Call2report Not tested, needs an USB GSM modem with Voice Call fucntion
		if (call2report) {
			businit();
			gn_call_check_active(state);
			pcall = gn_call_get_active(call_id);
			if (NULL != pcall) {
				printf("%d\n", (int) pcall->status);
				if (1==pcall->status /*&& 0 == strcmp(pcall->remote_number, number1)*/) {
					gn_call_cancel (call_id);
					usleep(10);
					cout<<"Call Received from Number: "<<pcall->remote_number <<endl;
					gn_call_cancel(call_id);
					usleep(10);
					cout<<"Sending SMS ..."<<endl;
					string report_sms="echo \"Temperature=" +to_string(current_tem) + " Humidity=" +to_string(current_hum)+" Gas_Levels="+to_string(current_gas)+ " Thermostat=" +(thermostat ? "ON" : "OFF")+ " Air Conditioner=" +
							+(ac ? "ON" : "OFF")+ " .Call2Report Service By Adil Benabdallah . \" | gnokii --sendsms " +string(pcall->remote_number);
					system(report_sms.c_str());
				}
			}
			busterminate();
			usleep(10);
		}
		usleep(10);
	}
	return 0;
}

static void businit(void) {
	if (GN_ERR_NONE != gn_lib_phoneprofile_load(NULL, &state))
		exit(2);
	if (GN_ERR_NONE != gn_lib_phone_open(state))
		exit(2);
}
static void busterminate(void) {
	gn_lib_phone_close(state);
	gn_lib_phoneprofile_free(&state);
	gn_lib_library_free();
}
/*void signal_handler(int signal) {
	quit = 1;
}*/

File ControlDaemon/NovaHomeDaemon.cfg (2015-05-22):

//Note: addresses are from 00 to 05 .
//For more than 6 addresses :  
///Node 00 is the base node.
///Nodes 01-05 are nodes whose parent is the base.
///Node 021 is the second child of node 01.
///Node 0321 is the third child of node 021, an so on.
	temp_h=3;            //Temperature  Hysteresis 
	ctemp_l=14;          //Critical Temperature (Low)
	ctemp_h=32;          //Critical Temperature (High)
	cgas=400;            //Critical Gas
	chumid=70;           //Critical Humidity 
	light_timer=10000     //auto-lights timer in milliseconds 
	hub_addr=00;         // Raspberry Pi RF address  
	sensor_addr=01;                                  
	ambient_addr=07;
	thermostat_addr=05;
	geolocation=false;		       // Geolocation function to get times for lights activation. 
	lights_off_ambient_on="23:00";         
	lights_off_ambient_off="7:00";         // Hour of lights off if geolocation is disabled
	lights_evening="19:00";                // Hour of lights on  if geolocation is disabled
	city_name="Tlemcen";                   // Comment this line if you want Geolocalisation 
	           
	call2report=false;                     // Needs testing, keep it false.
	day_saving=false;		       // Controls lights when the sun is still up 
	alert_phones=["055646565","05554555"];    // Add phone numbers for Fire and Smoke alerts 
	pirSwitchPairs = ( { pir_addr= 03; light_addr = 02 ;} 
                      ,{ pir_addr= 04; light_addr = 05 ;}
                      ,{ pir_addr= 07; light_addr = 01 ;}); 
                      // Write lines like this line if you want to add more PIR/Light pairs
         

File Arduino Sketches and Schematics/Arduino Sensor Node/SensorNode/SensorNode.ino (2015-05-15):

////////////////////////////////////////////////////////////////////////////////////////////////////////////////////////////
////**************************************** RF Sensor Node ********************************************************///////
////***************************************** By S!N0VA ************************************************************///////
////////////////////////////////////////////////////////////////////////////////////////////////////////////////////////////

#include <RF24Network.h>
#include <RF24.h>
#include <SPI.h>
#include <math.h>
#include <AES.h>
#include "./printf.h"
#include <stdint.h>
#include <HomeRF.h>
#include <sha1.h>
#include <TrueRandom.h>

/////////////////////////////////////Encryption setup
AES aes;
int bits = 128;
uint8_t hmacKey1[] = { 0x00, 0x01, 0x02, 0x03, 0x04, 0x05, 0x06, 0x07, 0x08,
		0x09, 0x0a, 0x0b, 0x0c, 0x0d, 0x0e, 0x0f, 0x10, 0x11, 0x12, 0x13, 0x14,
		0x15, 0x16, 0x17, 0x18, 0x19, 0x1a, 0x1b, 0x1c, 0x1d, 0x1e, 0x1f, 0x20,
		0x21, 0x22, 0x23, 0x24, 0x25, 0x26, 0x27, 0x28, 0x29, 0x2a, 0x2b, 0x2c,
		0x2d, 0x2e, 0x2f, 0x30, 0x31, 0x32, 0x33, 0x34, 0x35, 0x36, 0x37, 0x38,
		0x39, 0x3a, 0x3b, 0x3c, 0x3d, 0x3e, 0x3f };
byte key[] = { 0x53, 0xDE, 0xF0, 0x33, 0x7F, 0x1E, 0x59, 0xB3, 0x0A, 0x38, 0xF4,
		0xC0, 0x11, 0x81, 0xFE, 0x9C };



////////////////////////////////////////////RF Setup 
RF24 radio(7,8);                    // nRF24L01(+) radio attached using Getting Started board 
RF24Network network(radio);          // Network uses that radio
const uint16_t this_node = 01;        // Address of our node in Octal format
const uint16_t hub_addr = 00;       // Address of the other node in Octal format

void setup(void)
{  
  pinMode(HOUT_PIN, OUTPUT);
  pinMode(HIN_PIN, OUTPUT);
  pinMode(3, OUTPUT);
  pinMode(0,OUTPUT);
  digitalWrite(0,HIGH);  
  SPI.begin();    
  radio.begin();
  network.begin(/*channel*/ 90, /*node address*/ this_node);
   Serial.begin(57600);
   //Entropy.initialize(); 
  //Serial.println("Sensor Node Started ...");
}
int long timer=millis();


void loop() {

  
  //  Serial.println(millis()-timer);
  if (millis()-timer>60000)  { // Delay of one minute so the MQ2 heats up and give accurate readings .
      Serial.println("**********************************************************");
    float gas=0; for(int i=0;i<10;i++) {
      gas = gas + analogRead(MQ2_PIN);
    }
    gas=gas/10;
    float cap=0;
    for (int i=0;i<20;i++) {
      cap=cap+capacitance(); 
    }  
    cap=cap/20.0;
    float temp=0;
    for (int i=0;i<20;i++) {
      temp=temp+temp_c(); 
    }
  if (gas>600.0) digitalWrite(3,HIGH);else digitalWrite(3,LOW);
  temp=temp/20.0;
  Serial.print("Sending... ");
  unsigned long int my_iv_ =TrueRandom.random();
  Serial.print("Random IV :"); Serial.println(my_iv_);
  Serial.print("Temperature : ");
  Serial.print(temp);Serial.println(" °C");
  Serial.print("Gas Density : ");
  Serial.print(gas);Serial.println("ppm");
  Serial.print("Capacitance : ");
  Serial.print(cap); Serial.println("uF");
  float hum= map (cap,170,195,20,90) ;
  sensor_data plain_data ={temp,hum,gas} ;
  Serial.print("Sensor Data : ");
  PrintHex8((uint8_t*)&plain_data,sizeof(plain_data));
  byte sensor_bytes[sizeof(sensor_data)];
  memcpy(sensor_bytes, &plain_data, sizeof(sensor_data));
  byte iv [16] ;
  byte cipher[16];
  aes.set_IV(my_iv_);
  aes.get_IV(iv);  
  aes.do_aes_encrypt(sensor_bytes,sizeof(sensor_bytes),cipher,key,bits,iv);  
  
  aes_paquet aespaquet ;
  aespaquet.i_v=my_iv_;
  aespaquet.padding[0]=254;
  aespaquet.padding[1]=254;
  aespaquet.padding[3]=254;
  aespaquet.paquet_type='S';
  memcpy(aespaquet.enc_data,cipher,sizeof(aespaquet.enc_data));
  rf_paquet rfpaquet ;
  rfpaquet.aespaquet = aespaquet;
  Sha1.initHmac(hmacKey1,64);
  Sha1.print((const char*)&rfpaquet.aespaquet);
  memcpy(rfpaquet.hmac_tag,Sha1.resultHmac(),sizeof(rfpaquet.hmac_tag));
  Serial.print("HMAC tag : ");
  PrintHex8(rfpaquet.hmac_tag,20);
  Serial.print("AES paquet in hex : ");
  PrintHex8((uint8_t*)&aespaquet,sizeof(aespaquet));
  Serial.print("All paquet in hex : ");
  PrintHex8((uint8_t*)&rfpaquet,sizeof(rfpaquet));
  
  network.update();
  RF24NetworkHeader header( hub_addr);
  bool ok=network.write(header,&rfpaquet,sizeof(rfpaquet));   // Sending the Sensor Node RF packet
  delay(2000);                                                // Send every 2 seconds
   }
}

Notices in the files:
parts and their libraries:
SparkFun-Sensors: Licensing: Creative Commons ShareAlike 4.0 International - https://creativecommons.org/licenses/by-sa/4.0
